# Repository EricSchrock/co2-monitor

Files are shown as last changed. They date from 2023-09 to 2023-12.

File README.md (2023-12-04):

# CO2 Monitor

The goal of this project is to create a network of CO2 sensors for indoor air quality monitoring. See our [project proposal](https://github.com/EricSchrock/co2-monitor/blob/main/submissions/proposal.pdf) and [project report](https://github.com/EricSchrock/co2-monitor/blob/main/submissions/report.pdf) for more detail on our motivation, goals, design, and results.

&nbsp;
## Design

Our system is composed of a variable number of sensor units, which wirelessly report CO2 readings back to a base station. The base station presents these readings via a locally hosted website.

The base station is a Raspberry Pi 4B. We considered a range of [microcontrollers](https://github.com/EricSchrock/co2-monitor/blob/main/docs/microcontroller.md) and [CO2 sensors](https://github.com/EricSchrock/co2-monitor/blob/main/docs/co2-sensor.md) for the sensor unit. We settled on the Raspberry Pi Pico W connected to a Sparkfun ENS160 sensor over I2C.

| System | Sensor Unit |
|---|---|
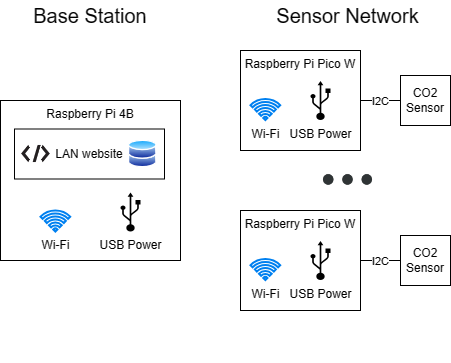
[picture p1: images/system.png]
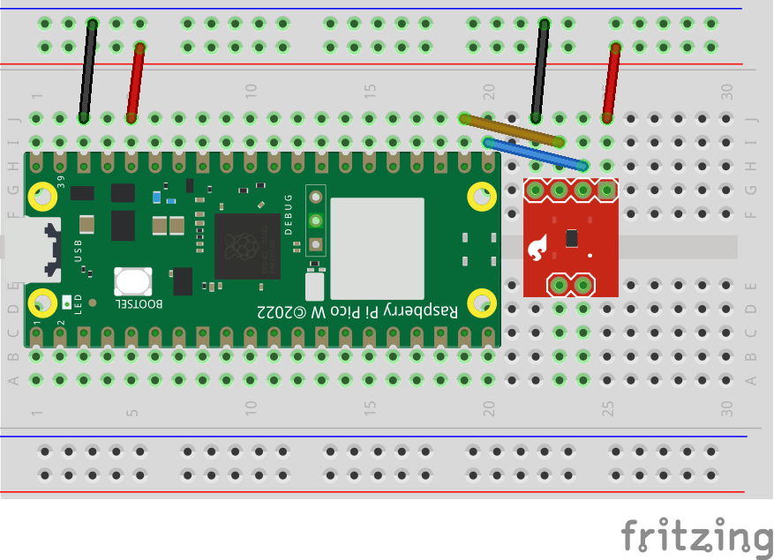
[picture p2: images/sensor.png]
|  |  |

Note: The CO2 sensor shown in the Fritzing diagram above does not match the actual part and is only meant to give a general sense of the design.

&nbsp;
## Bill of Materials (BOM)

### Base Station

| Part | Price* | Supplier  | Link |
|---|---|---|---|
| Raspberry Pi 4B (8 GB) | $75.00 | PiShop.us | https://www.pishop.us/product/raspberry-pi-4-model-b-8gb/ |
| 15W power supply |  $8.00 | PiShop.us | https://www.pishop.us/product/raspberry-pi-15w-power-supply-us-white/ |
| Case |  $5.00 | PiShop.us | https://www.pishop.us/product/raspberry-pi-4-case-red-white/ |
| **Total** | $88.00 | | |

*Price does not include shipping or bulk discounts.

### Sensor Unit

| Part | Price* | Supplier  | Link |
|---|---|---|---|
| Raspberry Pi Pico WH |  $7.00 | PiShop.us | https://www.pishop.us/product/raspberry-pi-pico-wh/ |
| 12.5W power supply |  $8.00 | PiShop.us | https://www.pishop.us/product/raspberry-pi-12-5w-power-supply-us-white/ |
| Sparkfun ENS160 | $19.95 | SparkFun  | https://www.sparkfun.com/products/20844 |
| Half sized bread board |  $4.75 | PiShop.us | https://www.pishop.us/product/half-size-400-pin-diy-breadboard-white/ |
| Breadboard wire kit**  |  $2.32 | PiShop.us | https://www.pishop.us/product/breadboard-wiring-kit/ |
| Headers for ENS160** |  $0.35 | PiShop.us | https://www.pishop.us/product/break-away-headers-40-pin-male-long-centered-pth-0-1/ |
| **Total** | $42.37 | | |

*Price does not include shipping or bulk discounts. \
**One set is enough to furnish at least three sensor units. Price divided by three.

### System

One system with a base station and three sensor units would cost $215.11 (not accounting for shipping). A productionized system could cost much less by buying in bulk and by using a less powerful Raspberry Pi (e.g. less RAM) in the base station. A productionized system would need to add a protective case for the sensor units.

&nbsp;
## Installation

See [src/README.md](https://github.com/EricSchrock/co2-monitor/blob/main/src/README.md) for instructions on setting up the sensor units, server, and web viewer.

&nbsp;
## Tasks

Hardware
  - [x] [First prototype: Just get something working](https://github.com/EricSchrock/co2-monitor/blob/main/docs/first-prototype.md)
    - [x] Diagram initial system architecture
    - [x] Diagram initial sensor unit
    - [x] [Choose which microcontroller to use for the sensor unit](https://github.com/EricSchrock/co2-monitor/blob/main/docs/microcontroller.md)
    - [x] [Choose which CO2 sensor to use](https://github.com/EricSchrock/co2-monitor/blob/main/docs/co2-sensor.md)
    - [x] Create parts list (including tools)
    - [x] Research/test whether to put a capacitor on the power rail between the microcontroller and CO2 sensor (some microcontrollers have built in capacitance on their power outputs)
    - [x] Research/test whether pull up resistors are needed on the I2C SDA and SCL lines between the microcontroller and CO2 sensor (some microcontrollers have built in or configurable pull ups on pins)
  - [x] Second prototype: Consider cost, size, and power usage
    - [x] Choose breadboard size (mini, tiny, half, or half+)
    - [x] Bill of Materials (BOM) including costs, part numbers, and supplier links

Software
  - [x] Sensor readings displayed on sensor unit (via debugger, attached LCD, etc.)
  - [x] Sensor readings displayed on base station (over wifi)
  - [x] Sensor readings displayed on locally hosted website served from the base station
    - [x] Live readings
    - [x] Historical trends
    - [x] Multiple sensors
  - [x] Diagrams (flow charts, activity diagrams, and/or sequence diagram)
    - [x] Sensor unit (sensor.py)
    - [x] Base station (server.py)
    - [x] Whole system

&nbsp;
## Resources

 - <https://www.raspberrypi.com/documentation/microcontrollers/raspberry-pi-pico.html>
 - <https://projects.raspberrypi.org/en/projects/getting-started-with-the-pico/0>
 - <https://datasheets.raspberrypi.com/picow/connecting-to-the-internet-with-pico-w.pdf>
 - <https://cdn.sparkfun.com/assets/3/c/7/5/5/SC-001224-DS-7-ENS160-Datasheet.pdf>

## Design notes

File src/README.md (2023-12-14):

# Sensor Setup

Modify `sensor/config.py` to set `SSID` and `PWD` to match the wifi network
your server is connected to. Set `IP` to the IP of the server and choose a
`PORT` number.

Save `sensor/config.py`, `sensor/ens160.py`, and `sensor/main.py` to the Raspberry
Pi Pico WH on each sensor. One way to do this is with the [Thonny](https://thonny.org/)
editor. The Pico will run `main.py` on power on.

Plug all your sensors into power. The LED on the Pico will blink until a wifi
connection is complete and then stay on until it connects to the server. Then
it will blink each time data is transmitted.

# Server Setup

## Configure Server

Modify the file `server/config.py` to set the Server IP address and Port.
These values must match the configuration hardcoded in the sensors.

Additionally, set the `SENSORS` value to the number of sensors that will be
connected to the system and set the `LOG_PATH` to the full path desired for log
output.

##  Run Server

```sh
python3 server/server.py
```

Add the following line to `/etc/rc.local` to start the server on power on.

```sh
python3 /<full>/<path>/<to>/<repo>/co2-monitor/src/server/server.py &
```

If you have issues with the server dying after a few hours, schedule a reboot
every hour by adding the `0 * * * * root reboot` cron job.

```sh
sudo nano /etc/crontab
```

# Web Viewer Setup

## Create and activate the venv

```sh
python3 -m venv .venv
source .venv/bin/activate
```

## Install requirements

```sh
python3 -m pip install -r requirements.txt
```

## Configure Web Viewer

Modify the dictionary in in `viewer/config.py` to map the sensor
unique IDs to more useful identifiers to be displayed in the webpage.

The unique IDs for the sensors connected to your system can be found
in the server log at `$HOME/.co2_data/server.log`.

## Run Web Viewer for development

To start the web viewer in development mode, run

```sh
flask -A viewer run --debug
```

This will start the http server on you local host at
`http://127.7.7.1:5000`.

## Run Web Viewer for deployment

To start the web viewer in deploy mode, start the http server using
`waitress` with

```sh
waitress-serve viewer:app
```

This will start the http server on `http://0.0.0.0:8080`, which will
serve the webpage from all IP addresses on your pi on port 8080. You can
navigate to `http://<rpi hostname>.local:8080` or `http://<rpi IP>:8080`
to view the web page.

## Using the Web Viewer

The web viewer will default to showing you a chart with all sensor values for
the current day. Using the available form fields, you can optionally specify to
view specific sensors or any other date. If no sensor data is available for the
selected date and sensor, no image will be shown.

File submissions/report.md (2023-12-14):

% **CS 437: Internet of Things** \
  **Final Project Report**
---
urlcolor: cyan
---

## Team

* Eric Schrock (ejs9)
* Devin Schmitz (devinms3)

## Overview

We created a distributed network of CO2 sensors that report back via wifi to a central hub. The hub exposes a web interface on the LAN for accessing the data. This allows us to track variations in CO2 levels throughout a home and over time. This data could be used to understand and improve indoor air quality, leading to healthier lives.

## Motivation

Breathing is one of the most fundamental processes of our lives, but most homes
are only equipped with smoke and carbon monoxide detectors, which just warn
against critically dangerous levels of air polution. High levels of pollutants
like Carbon Dioxide (CO2), particulate matter (PM), and volatile organic
compounds (VOCs) can go unnoticed, contributing to drowsiness, illness, and
poor cognitive function, among many other potential poor health
outcomes[^20][^21][^22].

Large pollutants can be filtered out by a good HVAC or air filtration system,
but small asphyxiants such as CO2 and VOCs are best managed with proper air
ventilation. However, the exchange of fresh outdoor air for indoor air works
against the mission of modern HVAC, door, and window systems, which attempt to
maintain a consistent internal climate (in spite of the surrounding
environment) by _avoiding_ the exchange of indoor and outdoor air.

It is easy to open a window during the spring and fall when the weather is
nice, but knowing when it is necessary to open a window for proper air
circulation during the cold winter or hot summer can be a challenge. Having a
window open all the time wastes energy heating excess fresh air, but fatigue
and headache from poor air quality only exacerbates common ailments like
seasonal depression.

The first step to balancing this tension is having data. CO2 serves as a good
proxy for appropriate air ventilation in general. CO2 is a direct byproduct of
respiration and combustion, so indoor levels rise throughout the day as we
breath and use gas appliances like stoves, hot water heaters, and furnaces. By
monitoring indoor CO2 levels, we can have a better idea of when there is
adequate ventilation and when more fresh air exchange is needed.

However, proper air monitoring requires a distributed network. A single sensor,
though useful, does not provide a comprehensive picture of the air quality
throughout a home (especially in homes with poor overall ventilation). A
network of sensors also reduces inaccuracy due to any single faulty sensor
reading and keeps the system more robust to sensor failures. Additionally, many
existing air monitoring solutions are cost prohibitive to deploy across a home,
with individual sensors costing up to $230[^23] and coming with a list of extra
and unnecessary features like onboard data processing and display.

We designed a simple, low cost CO2 sensor that can be deployed throughout a
home for real time monitoring of air quality with a single central hub for
processing and displaying the data via a convenient web application on the
local area network.

[^20]: <https://ehp.niehs.nih.gov/doi/10.1289/ehp.1510037>
[^21]: <https://papers.ssrn.com/sol3/papers.cfm?abstract_id=4296077>
[^22]: <https://www.niehs.nih.gov/health/topics/agents/air-pollution/index.cfm>
[^23]: <https://www.airthings.com//wave-plus>

## Technical Approach

Our overall system consists of a base station connected to a network of sensors over wifi. The base station is a Raspberry Pi 4B running a server. Sensors connect to the server and periodically report CO2 measurements. The base station then presents those measurements on a website available on the local area network.

Each sensor consists of a Raspberry Pi Pico WH connected to a CO2 sensor over I2C. Each sensor runs a client that is responsible for connecting to the server on the base station, reading CO2 measurements, and sending those measurements to the base station.

System Architecture

Sensor Layout[^52]

[^52]: The CO2 sensor shown in figure 2 does not match the actual part and is only meant to give a general sense of the design.

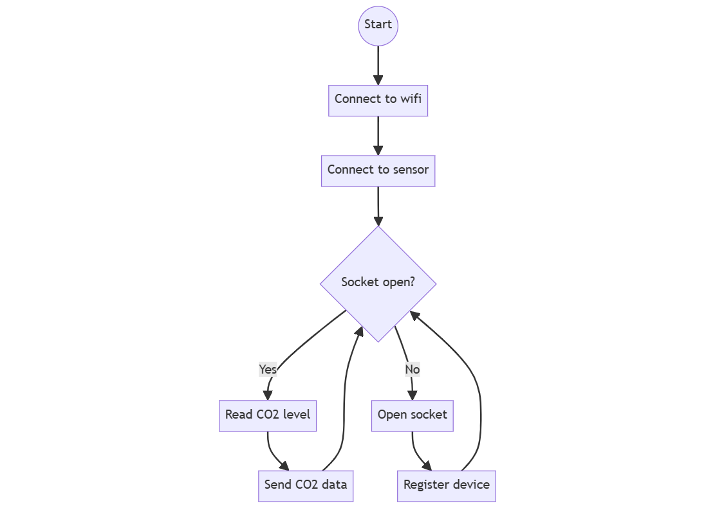
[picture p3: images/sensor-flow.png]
Sensor Flowchart


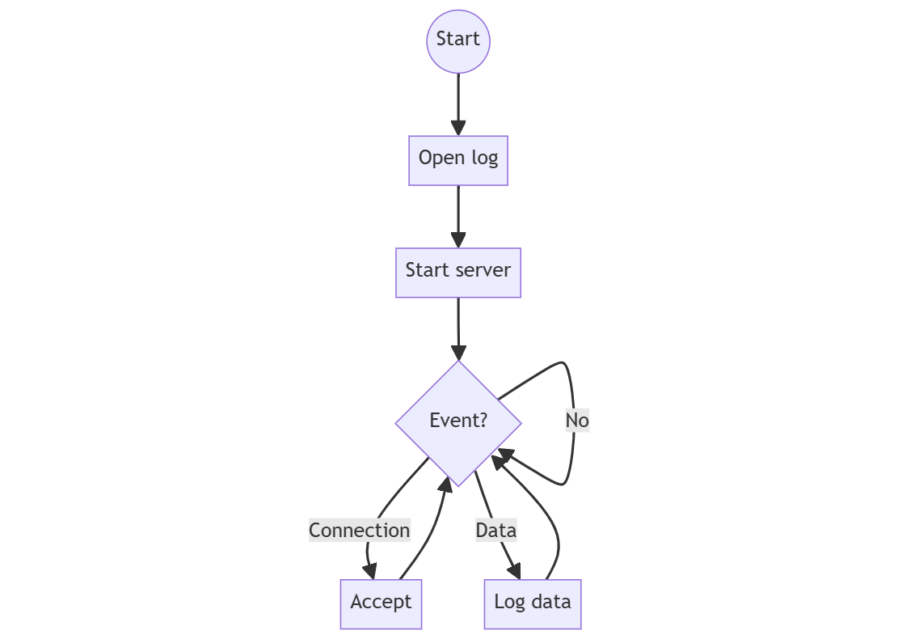
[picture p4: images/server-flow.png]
Server Flowchart


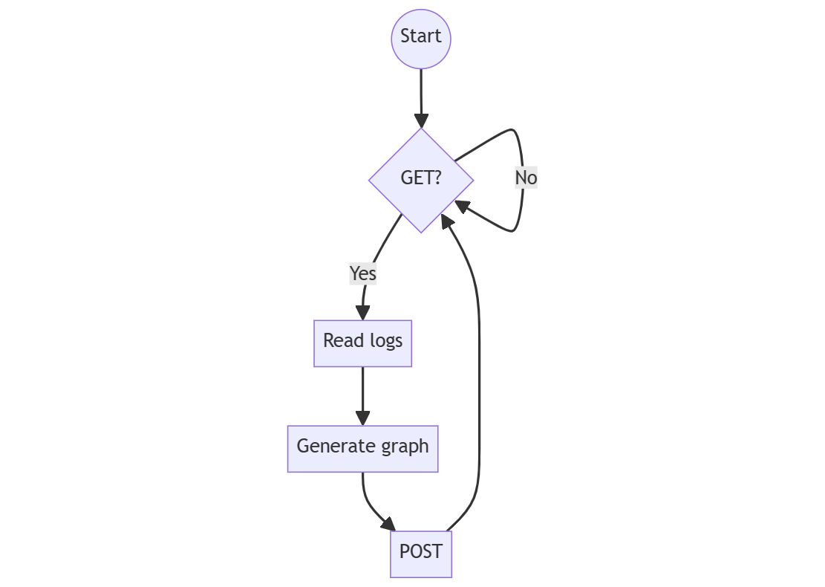
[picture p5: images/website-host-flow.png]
Website Host Flowchart


\pagebreak
## Implementation Details

### Sensors

We spent a significant amount of time comparing[^1] different options for the microcontroller on our sensors units. We started our search with six different Arduino variants (five Nano variants and the Micro). We looked at price, availability, breadboard compatibility, power and IO options, and connectivity (wifi, Bluetooth, and BLE). We were leaning towards the Arduino Nano 33 IoT[^2] when we found the Raspberry Pi Pico WH[^3] [^4], which checked all our boxes but for a much cheaper price ($7 vs $27).

[^1]: <https://github.com/EricSchrock/co2-monitor/blob/main/docs/microcontroller.md>
[^2]: <https://store-usa.arduino.cc/products/arduino-nano-33-iot-with-headers>
[^3]: <https://www.raspberrypi.com/documentation/microcontrollers/raspberry-pi-pico.html>
[^4]: <https://www.pishop.us/product/raspberry-pi-pico-wh-pre-soldered-headers>

The Pico comes with both C/C++[^5] and Python[^6] SDKs. We are both embedded C programmers for our day job, so we picked the Python SDK to get some experience with MicroPython[^7]. Additionally, the simplicity of Python fit with a simple prototype on a tight timeline.

[^5]: <https://datasheets.raspberrypi.com/pico/raspberry-pi-pico-c-sdk.pdf>
[^6]: <https://datasheets.raspberrypi.com/pico/raspberry-pi-pico-python-sdk.pdf>
[^7]: <https://micropython.org/>

We also considered[^8] multiple CO2 sensors, before settling on the ENS160[^9]. Our criteria were price, availability, breadboard compatibility, and power and IO options.

[^8]: <https://github.com/EricSchrock/co2-monitor/blob/main/docs/co2-sensor.md>
[^9]: <https://www.sciosense.com/wp-content/uploads/documents/SC-001224-DS-9-ENS160-Datasheet.pdf>

Additionally, we had to consider whether to choose a true CO2 sensor or an equivalent CO2 (eCO2[^10]) sensor. eCO2 sensors don't measure CO2 directly. Instead, they measure total volatile organic components (TVOC) and use that measurement to estimate the CO2 level. eCO2 sensors are much cheaper but are less accurate. We chose to go with an eCO2 sensor, as price is a big factor in our design. Having multiple sensor units allowed us to sanity check the reported values and notice anomalies. Given this, the eCO2 sensor was accurate enough to observe trends and draw conclusions. More on this in the CO2 Data Analysis portion of the Results section.

[^10]: <https://electronics360.globalspec.com/article/17986/what-are-eco2-sensors>

The SparkFun ENS160[^11] came with the option to communicate over I2C or SPI. We chose I2C because it was simpler to implement in MicroPython.

[^11]: <https://www.sparkfun.com/products/20844>

The Pico supports wifi, Bluetooth, and BLE. We initially planned to use BLE to communicate with the server, but implementing wifi communication turned out to be much simpler. Additionally, power usage turned out to be less of a concern than we initially thought because we chose to power the sensor units off wall power instead of batteries.

We chose to connect up the Pico and ENS160 on a half sized breadboard and to power them both through the micro USB port on the Pico. We built both dev units and full prototypes.

Development Unit
Full Prototypes
\begin{figure}[!h]
\caption{Development Unit (left) and Full Prototypes (right)}
\end{figure}

The software development for the sensor unit was relatively straight forward. We wrote simple programs to aid hardware bring up, first to blink the Pico LED and then to turn the Pico LED on when we breathed on the CO2 sensor. Then we created a simple program that connects to wifi, connects to the CO2 sensor via I2c, connects to the server, and then periodically reads and reports the CO2 level (see the sensor flow chart above in the Technical Approach section).

### Server

In choosing the hardware for the central server, we quickly decided to use the
Raspberry Pi 4B[^41] that we had both already purchased for earlier labs in the
class. The Raspberry Pi 4B provides a builtin wifi module to connect to the
sensor units and sufficient processing power and RAM to host a basic webpage
and do minimal data processing. In fact, the Raspberry Pi 4B far exceeded our
basic requirements for a server. If we were going to productionize the system,
we would explore using a smaller Raspberry Pi with less RAM or potentially an
even simpler SBC to reduce the cost of the system.

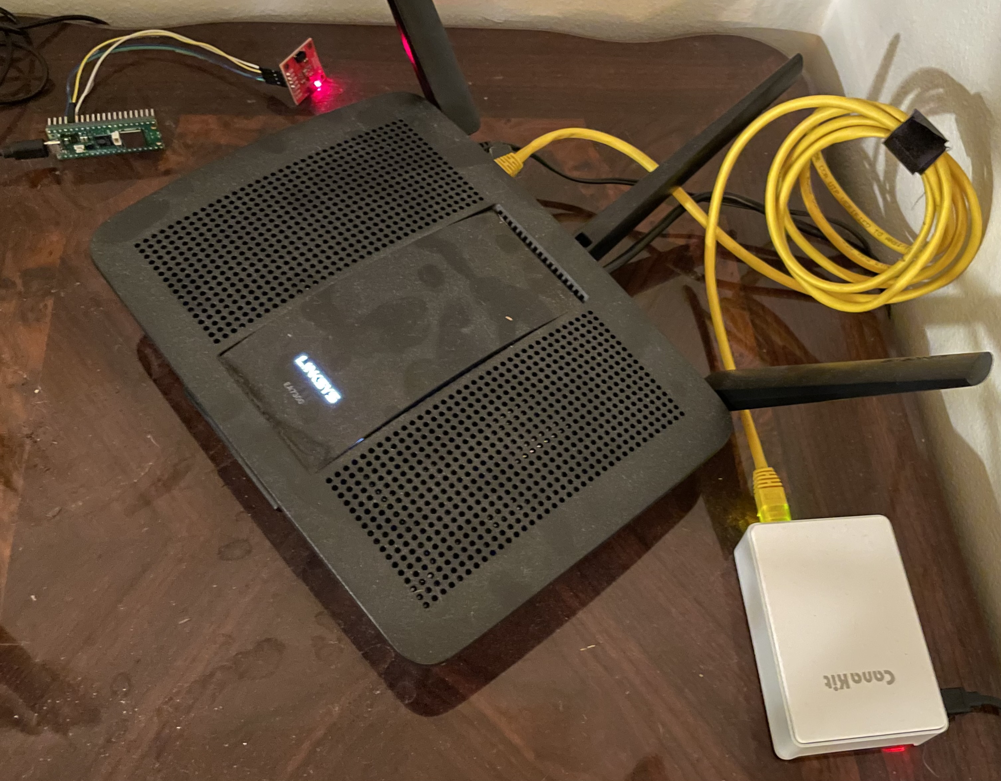
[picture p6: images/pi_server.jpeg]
Devin

Eric
\begin{figure}[!h]
\caption{Raspberry Pi Hubs Connected to Sensors via Wifi}
\end{figure}

In designing the server software, our goal was simplicity, reliability, and
minimal dependencies. We wrote the entire server application using just the
Python standard library. We started with a simple server that could connect to
one sensor using sockets, using what we had learned from our previous labs.
Then, we extended the server and our knowledge of sockets programming by
incorporating a selector[^42] to handle multiple socket connections to
different sensors. Throughout the server development, we took advantage of the
ability to create socket pairs on a single device to emulate a sensor network
locally for debugging, which allowed us to parallelize the sensor and server
development.

When it came to storing CO2 data, we considered integrating a proper database.
However, after looking into it, even a simple SQL database[^43] seemed like
unnecessary overhead and complexity for the data we were storing. We settled on
storing the data in basic CSV files to make both writing the data and loading
it for later analysis easy. Our first iteration of data logging had a unique
file for each sensor, which contained the full date-time timestamp for each CO2
reading. It quickly became apparent that this was suboptimal for two reasons.
First, having all CO2 data from one sensor in a single file meant that
significantly more data would have to be parsed to analyze a small time window
of data. Second, including the date in every timestamp was a significant
duplication of data and thus waste of memory. We settled on splitting up the
data by date instead, so that each day's readings would be stored in a
directory with a CSV file for each sensor that only contained the timestamps
for the CO2 readings.

One challenge I (Eric) faced was the server process on the Pi dying every few hours. My solution was to reboot the Pi every hour via the Linux `cron` utility. I edited `/etc/rc.local` to restart the server on each reboot, allowing me to capture data over long periods without babysitting (e.g overnight). Devin's system never exhibited this issue.

[^41]: <https://www.raspberrypi.com/products/raspberry-pi-4-model-b/>
[^42]: <https://docs.python.org/3/library/selectors.html>
[^43]: <https://docs.python.org/3/library/sqlite3.html>

### Website

Since neither of us has web development experience, we were learning
everything as we went. This meant simplicity and basic functionality were high
priorities as we chose software stacks for our web application. We are both
comfortable with Python, so it made sense to use a backend Python framework. We
considered two dominant web frameworks: Django[^31] and Flask[^32]. Each has
pros and cons, and both are widely used in industry. However, we settled on
Flask for two key reasons. First, it is faster to get a minimal web application
up and running from scratch in Flask. Second, Flask uses `jinja2`[^37]
templates by default, which we were already familiar with.

From there, the development of the website evolved in stages. First, we setup
a basic "Hello World" page to verify that we could successfully run our Flask
application. Then, we upgraded the application to include a request form for a
date, which we initially just echoed to the webpage. Finally, we updated the
web app to display the list of CO2 reading times and values for the selected
date.

At this stage, we had to decide on a software stack to generate the most
important part of the web application: a chart of the data. We considered
three options: Chart.js[^33], Matplotlib[^34], and plotlib[^35] with
WebAssembly[^36]. These three options vary significantly, from the language
used (Javascript, Python, and Rust respectively) to how they integrate into the
Flask application. While the Rust and WebAssembly option was interesting to
explore, WebAssembly is a relatively new technology and doesn't have the same
level of existing examples and documentation as the more established
competitors. Chart.js was a compelling option, with support for dynamic and
interactive charts in a web-native language. However, Matplotlib had a few
great examples for integrating charts into a webpage and was already familiar
to us, so it won out as the best option to meet the goals and timelines of this
project. Additionally, in brief prototyping, a webpage with a matplotlib image
reloaded nearly instantaneously, while plotting the same data with Chart.js had
a noticeable (several second) delay.

Finally, we needed to choose a WSGI server to host our web application. We
considered several of the options on Flask's list of recommended self-hosted
WSGI servers[^38]. We chose Waitress[^39] because it is a pure Python
application with no dependencies, which made it easy to include in our project.

[^31]: <https://docs.djangoproject.com/en/5.0/>
[^32]: <https://flask.palletsprojects.com/en/3.0.x/>
[^33]: <https://www.chartjs.org/>
[^34]: <https://matplotlib.org/stable/index.html>
[^35]: <https://docs.rs/plotlib/latest/plotlib/>
[^36]: <https://rustwasm.github.io/>
[^37]: <https://jinja.palletsprojects.com/en/3.1.x/templates/>
[^38]: <https://flask.palletsprojects.com/en/3.0.x/deploying/>
[^39]: <https://docs.pylonsproject.org/projects/waitress/en/stable/>

## Results

### Project Timeline

Overall, the project probably took a little over the projected 45 hours. The bookends, the initial design decisions and the project report, took much more time than planned, but the hardware bring up was exceptionally smooth and we did not need the planned second prototype. Our time estimates for the website were about right.

### Project Objectives

At a high level, we met the objective we laid out in our project proposal, which was "to create a network of CO2 sensors with a web interface" to allow "distributed monitoring of indoor air quality." Our proposal also laid out the objectives of "simple, low cost, low energy" sensors.

We met the objective of simple sensors. We avoided extra functionality that would have increased cost and complexity (e.g. multi-function sensors or extra website features). We also kept the setup instructions[^12] simple (for a prototype).

[^12]: <https://github.com/EricSchrock/co2-monitor/blob/main/src/README.md>

As our design evolved from a battery powered sensor to a wall powered sensor, we dropped the objective of being low energy. This allowed us to make tradeoffs in favor of simplicity and speed. For example, it allowed us to keep our code simple by using wifi instead of BLE and by not implementing any low power modes. Now that we have a working prototype that has proved it's value, power usage optimization would be a valuable consideration for a second prototype.

We also met the objective of low cost sensors, with each sensor unit costing roughly $40. A productionized sensor unit, benefiting from economies of scale, could cost even less.

The base station prototype is pricier at $88. This is largely because we used the 8 GB Raspberry Pi 4B because it is what we had on hand. Using the 1 GB model would drop the base station cost to $48. A simple website doesn't take much compute power. A productionized version of the base station could use an even cheaper processor. It's even possible that one of the sensor units could function as the server for the rest of the sensor network.

**Sensor Unit**

| Part | Price[^44]  |
|---|---|
| Raspberry Pi Pico WH |  $7.00[^45] |
| 12.5W power supply |  $8.00[^46] |
| Sparkfun ENS160 | $19.95[^47] |
| Half sized bread board |  $4.75[^48] |
| Wires and headers | ~$0.30 |
| **Total** | $40.00 |

**Base Station**

| Part | Price[^44]  |
|---|---|
| Raspberry Pi 4B (8 GB) | $75.00[^49] |
| 15W power supply |  $8.00[^50] |
| Case |  $5.00[^51] |
| **Total** | $88.00 |

[^44]: Price does not include shipping or bulk discounts.
[^45]: <https://www.pishop.us/product/raspberry-pi-pico-wh/>
[^46]: <https://www.pishop.us/product/raspberry-pi-12-5w-power-supply-us-white/>
[^47]: <https://www.sparkfun.com/products/20844>
[^48]: <https://www.pishop.us/product/half-size-400-pin-diy-breadboard-white/>
[^49]: <https://www.pishop.us/product/raspberry-pi-4-model-b-8gb/>
[^50]: <https://www.pishop.us/product/raspberry-pi-15w-power-supply-us-white/>
[^51]: <https://www.pishop.us/product/raspberry-pi-4-case-red-white/>

\pagebreak
### CO2 Data Analysis

One question we had was whether our sensors would be accurate enough to provide useful data. We found that the data trends were reliable enough to interpret and act on. For example, figure 8 shows around thirteen hours of CO2 data that is readily attributable to the day's activities.

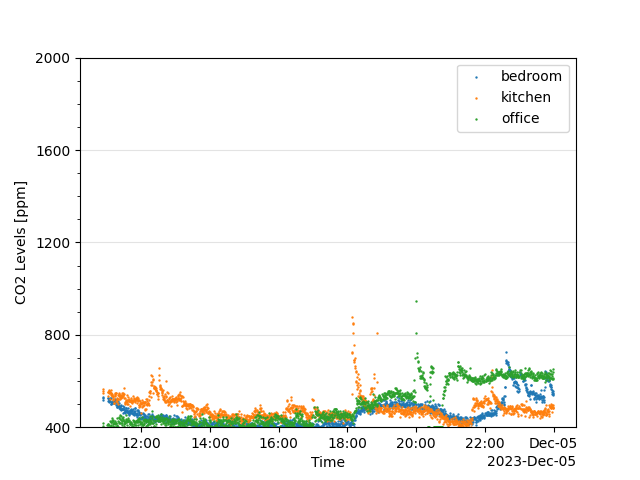
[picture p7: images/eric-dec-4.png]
CO2 Data from Eric's Home (12/4/23)


1. 11 AM - 2 PM: Bedroom CO2 level drops from its nighttime high.
2. 12 - 1 PM: Kitchen CO2 level jumps as my wife and I (Eric) eat lunch.
3. 1 - 6:15 PM: Bedroom sits empty and has the lowest CO2 level. I sit at my desk in my office and my wife moves around the kitchen and adjoining living room. The kitchen CO2 level is higher than the office CO2 level because humans breath out more CO2 when we are active.
4. 6:15 PM: Kitchen CO2 level spikes when we vent the pressure cooker and then dissipate to the rest of the house.
5. 6:30 - 7 PM: Kitchen CO2 level jumps as my wife and I eat supper.
6. 7 - 9:30 PM: My wife leaves for time with friends and I return to my office. Kitchen CO2 level drops below that of the office.
7. 8:15 PM: I briefly open a window in my office. The office CO2 level drops to the minimum sensor value of 400 ppm, but jumps back up as soon as I close the window.
8. 8:30 - 8:45 PM: I open a window in my office for 15 minutes. The office CO2 level again drops to the minimum, but jumps back as soon as the window is closed.
9. 9:30 - 10:15 PM: My wife returns and we spend time together in the living room, near the kitchen. The kitchen CO2 level jumps.
10. 10:15 PM: We go to bed. Kitchen CO2 level drops and bedroom CO2 level jumps.

The sensors do have a couple issues to keep in mind. First, as explained in the section on implementation details, they are measuring eCO2 which is an estimate of CO2 levels derived from TVOC levels. TVOCs can spike without CO2 spiking. For example, the data above shows a spike in the office CO2 levels at around 8 PM. This was from running a paper shredder near the sensor.

Second, the sensor results can occasionally get stuck at a high offset until they are power cycled. The CO2 level in the office jumped significantly the evening of December 4th (figure 8) and remained high into the next day (figure 9). I first tried opening windows throughout the house from 10:15 - 10:30 AM. The other rooms responded to this, but the office CO2 level jumped back up as soon as the windows were closed. At around noon, I power cycled the office sensor.

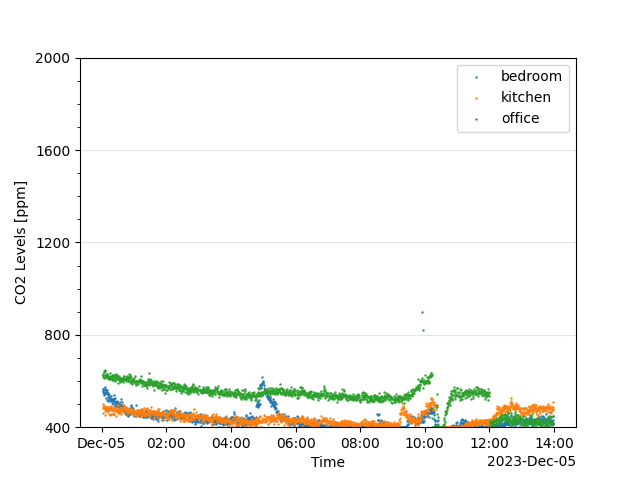
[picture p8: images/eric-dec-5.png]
CO2 Data from Eric's Home (12/5/23)


There were other interesting trends we observed in the data.
For example, the week of Thanksgiving I (Devin) was out of the home,
and all three CO2 sensors consistently measured low and unchanging CO2 levels (figure 10).
This indicates that practically all significant CO2 production in the home is
linked to my activity in some way, rather than to furnace or hot water heater
cycles.

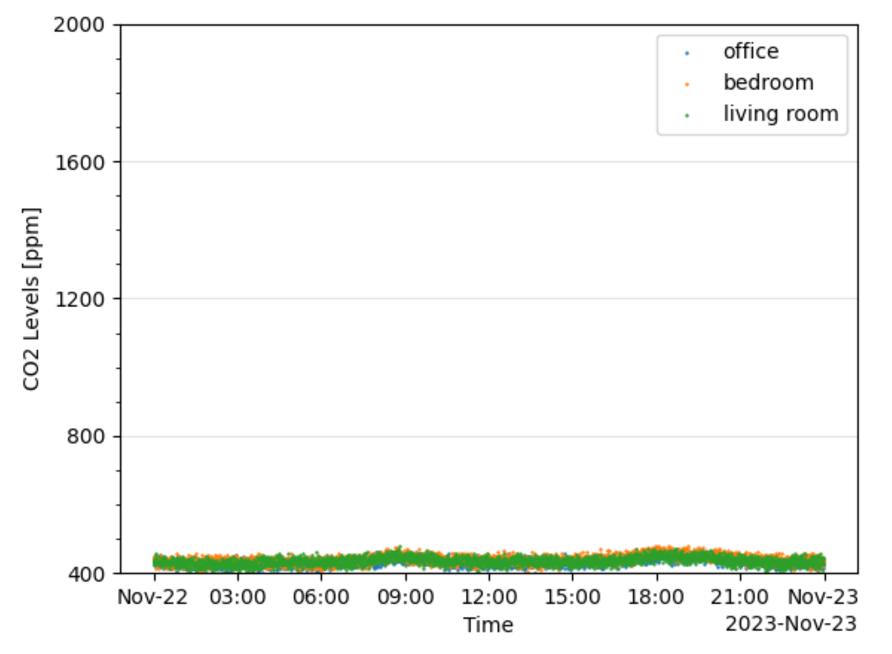
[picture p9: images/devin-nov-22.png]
CO2 from Devin's Vacant Home (11/22/23)


Another pattern I noticed is a cyclic rising and
falling CO2 levels in the bedroom during early morning hours (figure 11).
The cycles appear every night and only in the bedroom, leading
me to wonder if they are related to sleep cycles.
Correlating the data to a sleep tracker would be a fascinating follow on project.

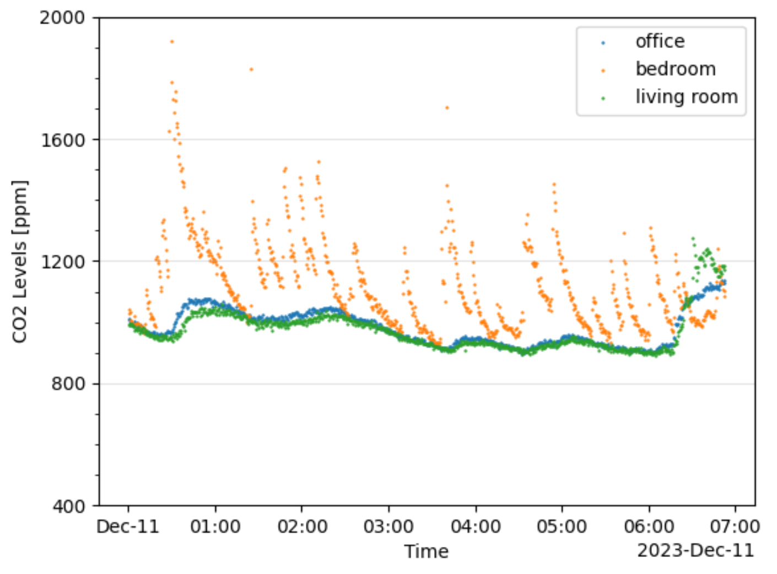
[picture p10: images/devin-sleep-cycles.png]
Cycling CO2 from Devin's Early Morning Bedroom


Despite some issues, our sensor data correlated well to real world events. As long as the limitations we listed are kept in mind, we believe it is accurate enough to drive meaningful decisions. Examples range from whether to open a window in the winter to whether to invest in a new HVAC that cycles in outdoor air in response to high indoor CO2 levels.

\pagebreak
## Demo Videos

We recommend watching these videos on a large screen and/or setting your video player to HD/1080p.

[Sensor Demo (part 1)](https://drive.google.com/file/d/1a0BKiZZGW25rD8P6CbH9XDvGnOE_0py2/view?usp=drive_link)

[Sensor Demo (part 2)](https://drive.google.com/file/d/1c5ptHw5lVUbp_UhcpIysfnRmQVWlg9hd/view?usp=drive_link)

[Server Demo](https://drive.google.com/file/d/1L9Yu0_yAXi-gdyQ4_XYW-zPx3bfIi20b/view?usp=sharing)

[Website Demo](https://drive.google.com/file/d/16GgEEeUNtK0YC5ep9FUWzXnTIX9rkhJd/view?usp=sharing)

## Project Repository

<https://github.com/EricSchrock/co2-monitor>

## What We Learned

### Eric

Two of the key skills I learned in this project were networking via the Python sockets library and how to configure Linux using the `/etc/rc.local` file and `cron` jobs. Both were completely new to me and are valuable experiences for the future.

On a different note, I was surprised by how easy it was to get the project up and running on the Raspberry Pi Pico with MicroPython. I'm used to embedded boards being much more painful to bring up. Perhaps some personal projects I thought would be too time consuming are actually in reach!

This project also taught me about the health impacts of high concentrations of CO2 in indoor spaces. This is important knowledge to help me stay sharp. As a remote worker, I can put what I've learned to use by opening my office windows at key times.

### Devin

I learned a great deal from working with the hardware in this lab. I soldered
header pins for the first time. I gained valuable experience reading the ENS160
datasheet to understand how to read sensor values over I2C. I learned how to
use `minicom` to view serial data from the Pi Pico and how to prototype
micropython on the Pi Pico from the interactive micropython REPL.

This project significantly expanded my understanding and confidence in socket
programming, which I had only just learned in previous class labs. It also
challenged me to write a safe and robust server application.

Building the webpage may have taught me the most. Weighing different Python web
frameworks gave great insight into the infrastructure underlying websites and
web applications that I use on a daily basis. Actually deploying a functional
web form involved more pieces than I knew and gave me a new respect for web
development.

### If We Had More Time

If we were to take this project further, we would have three main goals. The first would be to increase the accuracy of the sensor readings, either by tuning them with temperature and humidity readings reported to them by the base station or by automatically power cycling the ENS160 CO2 sensor periodically.

Second, we would expand the functionality of the website. We would add the ability to save timestamped notes to mark and explain phenomena in the data. We would also make the time interval for the display configurable. Additionally, we would add simple statistics, such as the max and average over the selected time interval.

The third goal would be to condense the sensor unit into a wall wart with a protective housing. We would look into 3D printing for the case and into a custom PCB to fit in a smaller form factor.

## Conclusion

In conclusion, we accomplished the high level goal of our project, to prototype a distributed, networked, and affordable CO2 monitoring solution. Along the way, we tried new technologies, built new skills, and gained a deeper understanding of the quality of the air in our homes and of how it impacts our health.

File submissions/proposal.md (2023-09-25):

% **CS 437: Internet of Things** \
  **Final Project Proposal**
---
urlcolor: cyan
---

## Overview

We propose to create a network of CO2 sensors with a web interface. Our goal is
distributed monitoring of indoor air quality.

## Group

One of the motivations of this project is to stretch us beyond what we already know. We have included short professional biographies to illustrate our current skills and how we hope this project extends them.

### Eric Schrock (ejs9)

My Computer Engineering curriculum was a mixture of Electrical Engineering and Computer Science in addition to courses on embedded programming and digital logic design. After graduation, I spent four years in the automotive industry working on advanced driver-assistance systems (ADAS). Devin and I now work together on the root of trust (RoT) for secure servers.

I am most comfortable programming bare metal (no OS) embedded C on microcontrollers. I've also played with various sensors and displays. I have very little experience with networking or web development and I anticipate our project challenging me to grow in these areas.

### Devin Schmitz (devinms3)

My formal Computer Science background consists of only a few introductory
programming courses, algorithms, and data structures, but I have a strong
background in applied mathematics and a broad knowledge of the physical
sciences. My professional experience is all centered around bare metal embedded
C, but I also have a fair knowledge of Linux operating systems and data
analysis with numerical Python. I anticipate most everything else involved in
the project will be a learning opportunity for me. In particular, I have very
little experience with networking and web development, and no experience with
javascript.

## Motivation

Breathing is one of the most fundamental processes of our lives, but most homes
are only equipped with smoke and carbon monoxide detectors, which just warn
against critically dangerous levels of air polution. High levels of pollutants
like Carbon Dioxide (CO2), particulate matter (PM), and volatile organic
compounds (VOCs) can go unnoticed, contributing to drowsiness, illness, and
poor cognitive function, among many other potential poor health
outcomes[^1][^2][^3].

Large pollutants can be filtered out by a good HVAC or air filtration system,
but small asphyxiants such as CO2 and VOCs are best managed with proper air
ventilation. However, the exchange of fresh outdoor air for indoor air works
against the mission of modern HVAC, door, and window systems, which attempt to
maintain a consistent internal climate (in spite of the surrounding
environment) by _avoiding_ the exchange of indoor and outdoor air.

It is easy to open a window during the spring and fall when the weather is
nice, but knowing when it is necessary to open a window for proper air
circulation during the cold winter or hot summer can be a challenge. Having a
window open all the time wastes energy heating excess fresh air, but fatigue
and headache from poor air quality only exacerbates common ailments like
seasonal depression.

The first step to balancing this tension is having data. CO2 serves as a good
proxy for appropriate air ventilation in general. CO2 is a direct byproduct of
respiration and combustion, so indoor levels rise throughout the day as we
breath and use gas appliances like stoves, hot water heaters, and furnaces. By
monitoring indoor CO2 levels, we can have a better idea of when there is
adequate ventilation and when more fresh air exchange is needed.

However, proper air monitoring requires a distributed network. A single sensor,
though useful, does not provide a comprehensive picture of the air quality
throughout a home (especially in homes with poor overall ventilation). A
network of sensors also reduces inaccuracy due to any single faulty sensor
reading and keeps the system more robust to sensor failures. Additionally, many
existing air monitoring solutions are cost prohibitive to deploy across a home,
with individual sensors costing up to $230[^4] and coming with a list of extra
and unnecessary features like onboard data processing and display.

We propose to address these issues by designing simple, low cost, low energy
CO2 sensors that can be deployed throughout a home for real time monitoring of
air quality, with a single central hub for processing and displaying the data
via a convenient web application on the local area network.

[^1]: <https://ehp.niehs.nih.gov/doi/10.1289/ehp.1510037>
[^2]: <https://papers.ssrn.com/sol3/papers.cfm?abstract_id=4296077>
[^3]: <https://www.niehs.nih.gov/health/topics/agents/air-pollution/index.cfm>
[^4]: <https://www.airthings.com//wave-plus>

\pagebreak

## Timeline

* Since we both lack web and networking experience, we set higher time estimates for related milestones
* "CP" stands for "Checkpoint"

+--------------+-------------------------------------------------+-----------+
| **Week**     | **Milestones**                                  | **Hours** |
+==============+=================================================+===========+
| 6            | - Initial design decisions                      |         4 |
|              | - Parts ordered for initial prototype           |         1 |
+--------------+-------------------------------------------------+-----------+
+--------------+-------------------------------------------------+-----------+
| 7            | - Components individually tested                |         4 |
|              | - Initial prototype built                       |         2 |
+--------------+-------------------------------------------------+-----------+
+--------------+-------------------------------------------------+-----------+
| 8            | - Local display of CO2 readings                 |         3 |
|              | - Test plan showing CO2 level variation         |         1 |
+--------------+-------------------------------------------------+-----------+
+--------------+-------------------------------------------------+-----------+
| **CP 1**     | **Local CO2 level display**                     |           |
+--------------+-------------------------------------------------+-----------+
+--------------+-------------------------------------------------+-----------+
| 9            | - Second prototype designed                     |         3 |
|              | - Parts ordered for second prototype            |         1 |
+--------------+-------------------------------------------------+-----------+
+--------------+-------------------------------------------------+-----------+
| 10           | - New components individually tested            |         3 |
|              | - Second prototype assembled and tested         |         2 |
+--------------+-------------------------------------------------+-----------+
+--------------+-------------------------------------------------+-----------+
| 11           | - LAN website displays live CO2 reading         |         5 |
+--------------+-------------------------------------------------+-----------+
+--------------+-------------------------------------------------+-----------+
| **CP 2**     | **LAN access to live data**                     |           |
+--------------+-------------------------------------------------+-----------+
+--------------+-------------------------------------------------+-----------+
| 12           | - Website shows historical trends               |         5 |
+--------------+-------------------------------------------------+-----------+
+--------------+-------------------------------------------------+-----------+
| 13           | - Website shows multiple sensors                |         5 |
+--------------+-------------------------------------------------+-----------+
+--------------+-------------------------------------------------+-----------+
| **CP 3**     | **Fully featured website**                      |           |
+--------------+-------------------------------------------------+-----------+
+--------------+-------------------------------------------------+-----------+
| 14           | - Design documents updated                      |         2 |
+--------------+-------------------------------------------------+-----------+
+--------------+-------------------------------------------------+-----------+
| 15           | - Final report and demo video                   |         4 |
+--------------+-------------------------------------------------+-----------+
+--------------+-------------------------------------------------+-----------+
| Hours        |                                                 |        45 |
+--------------+-------------------------------------------------+-----------+

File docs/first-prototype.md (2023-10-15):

# First Prototype

The goal of our first prototype is to just get something working. Additionally, we need to acquire and learn any tools we don't already have (soldering iron, logic analyzer, etc.).

&nbsp;
## Layout (sensor unit)



&nbsp;
## Parts List

Some of these items are optional. The parts list for the second prototype will be more precise.

| Item | Notes |
|---|---|
| Raspberry Pi 4B | |
| Raspberry Pi Pico WH | |
| USB-C cable for PI 4B | |
| Micro USB cable for Pico | Needs to support power and data |
| USB wall wart for Pico | Use wall power for sensor units |
| Sparkfun ENS160 | |
| Breadboard | Half or full size should work |
| Breadboard wire kit | |
| Resistor and capacitor kit | For pull ups and power smoothing |
| Soldering iron | For CO2 sensor |
| Soldering station | With clips to hold components |
| Oscope or logic analyzer | For I2C debugging |

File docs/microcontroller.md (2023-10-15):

## Microcontroller Comparison

| Microcontroller | Price* | Shipping  | Headers** | 3V3 | 5V  | I2C | BT  | BLE | Fritzing  | Link |
|---|---|---|---|-----|-----|---|-----|-----|---|---|
| Micro | $24.90 | 3 days | Yes | Yes | Yes | Yes |  No |  No | Yes**** | https://store-usa.arduino.cc/products/arduino-micro |
| Nano | $24.90 | 3 days | Yes | Yes | Yes | Yes |  No |  No | Yes | https://store-usa.arduino.cc/products/arduino-nano |
| Nano Every | $14.70 | 3 days | Yes | Yes | Yes | Yes |  No |  No | Yes**** | https://store-usa.arduino.cc/products/arduino-nano-every-with-headers |
| Nano 33 BLE | $29.30 | 3 days | Yes | Yes | Yes | Yes*** | Yes | Yes | Yes**** | https://store-usa.arduino.cc/products/arduino-nano-33-ble-with-headers |
| Nano 33 IoT | $27.00 | 3 days | Yes | Yes | Yes | Yes*** | Yes | Yes | Yes**** | https://store-usa.arduino.cc/products/arduino-nano-33-iot-with-headers |
| Nano ESP32 | $21.00 | 3 days | Yes | Yes | Yes | Yes | Yes |  No | No | https://store-usa.arduino.cc/products/nano-esp32-with-headers |
| RPi Pico WH |  $7.00 | 1-5+ days | Yes | Yes | Yes | Yes | Yes | Yes | Yes | https://www.sparkfun.com/products/20174 |

RPi Pico WH just went out of stock on Sparkfun, it is also available at
<https://www.pishop.us/product/raspberry-pi-pico-wh/>

*Does not include shipping \
**Breadboard compatible headers \
***Built in pull up resistors \
****Custom Fritzing part available to download

&nbsp;
## Microcontroller Choice

We started our search with the Arduino Micro and Nano because we want to keep our sensor units small and cheap. We plan to build our prototypes on small breadboards, so having pre-soldered headers that fit breadboard rails will keep things simple. We anticipate communicating with our CO2 sensor over I2C but we don't know yet whether the sensor we choose will require 3V3 or 5V power. Power usage is also a consideration for our project so we'd like to use BLE rather than vanilla Bluetooth or Wi-Fi if possible. We were initially leaning towards the Arduino Nano 33 IoT, but ended up landing on the Raspberry Pi Pico WH for the reasons below.

  - Low Cost: Only $7.00 per unit
  - Versatile Power input: 5V via micro USB or 1.8V - 5.5 V from any power
    source directly to VSYS (battery, etc.) with automatic conversion to 3V3
    via onboard buck-boost SMPS.
  - Full Wireless Capabilities: 2.4GHz wireless interface (Infineon CYW4343)
    - Single band (2.4 GHz) Wifi 4 (802.11n)
    - WPA3
    - softAP (up to 4 clients)
    - Bluetooth 5.2:
      - Support for Bluetooth LE Central and Peripheral roles
      - Support for Bluetooth Classic
  - Available with soldered 0.1 inch headers
  - 30 mulit-function GPIO with 1.8 - 3.3V I/O
  - 2 UART, 2 SPI, 16 PWM, 4 ADC channels
  - 1 timer with 4 alarms, 1 real time clock
  - 2 Programmable I/O (PIO) blocks, 8 state machines total
  - Fritzing Part: <https://www.raspberrypi.com/documentation/microcontrollers/raspberry-pi-pico.html>

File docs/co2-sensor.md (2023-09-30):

## CO2 Sensor Comparison

| Source | Price* | Shipping | Vin | IO  | Link |
|---|---|---|---|-----|---|
| Amazon | $13.99 | 1 day  | 3V3 or 5V | I2C | https://www.amazon.com/EC-Buying-Formaldehyde-Monitoring-Multi-Pixel/dp/B0B389LQCQ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 |
| Amazon | $21.99 | 2 days | 2-5V | I2C | https://www.amazon.com/Measurement-Quality-Dioxide-Detector-Replace/dp/B09SH53B58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 |
| Amazon | $13.36 | weeks  | ? | I2C | https://www.amazon.com/dp/B0CJR2SG1J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 |
| Arduino  | $48.90 | 3 days | ?** | ?** | https://store-usa.arduino.cc/collections/sensors/products/gravity-analog-co2-gas-sensor-mg-811-sensor |
| SparkFun | $19.95 |  5+ days | 3V3 | I2C | https://www.sparkfun.com/products/20844 |
| SparkFun | $29.95 |  5+ days | 3V3 | I2C | https://www.sparkfun.com/products/22858 |
| Adafruit | $44.95 | | 3.3-5V | I2C | https://www.adafruit.com/product/5187 |

*Does not include shipping \
**May require additional Arduino shield (compatible with Nano?)

&nbsp;
## CO2 Sensor Choice

Which CO2 sensor to use is a difficult choice. Well known suppliers like Arduino, SparkFun, and Adafruit likely have better support and documentation, but they are also more expensive and have costlier and slower shipping. Off brand Amazon options are cheap and ship quickly but who knows how well they work or how they they are documented.

There are a few options for CO2 sensing:
- Using "true" CO2 sensors
  - Pros: higher accuracy, direct CO2 measurement
  - Cons: more expensive
- Using "equivalent" CO2 sensors
  - Pros: Cheaper
  - Cons: Don't actually measure CO2, may require calibration, less accurate
- Using combination of "true" and "equivalent" CO2 sensors
  - Pros: single "true" sensor can be used to calibrate "equivalent" sensors
  - Cons: Even a single "true" unit is pretty expensive, extra work to
    integrate two different types of sensors

For this project, the goal is not perfect sensing but instead relative sensing
over time to get a sense of overall air circulation. Because of this, the cost
savings of cheaper CO2 equivalent sensors better meet the needs of the project
than the more accurate true CO2 sensors. Additionally, with multiple sensors
calibration can be done over all the sensors in the same environment, allowing
slight variations per sensor to be balanced out over the whole sensor group.
This means the highest priorities are cost, compatibility, and ease of use.

In the equivalent CO2 sensor space, the
[ENS160](https://www.sciosense.com/wp-content/uploads/documents/SC-001224-DS-9-ENS160-Datasheet.pdf)
appears to offer the perfect balance of quality, cost, and ease of use. For our
system, we are not able to directly solder sensors to our microcontroller PCB,
so we need to buy the sensor on a prefabricated chip with easy pin access. Both
[Sparkfun](https://www.sparkfun.com/products/20844) and
[Adafruit](https://www.adafruit.com/product/5606) offer the ENS160 presoldered
in a convenient package, though at more than double the price of the sensor
itself. Pairing the ENS160 with a temperature and humidity sensor can increase
the accuracy of the results, but for the same price it would be possible to
move into the true CO2 sensing space. We could also have a "central" Humidity
and temperature sensor, say at the hub, that transmits to all of the networked
CO2 sensors using the assumption that the indoor climate is approximately the
same for all sensors.

To move into true CO2 sensors, the
[SCD4x](https://sensirion.com/media/documents/48C4B7FB/64C134E7/Sensirion_SCD4x_Datasheet.pdf)
range of sensors provide varying degrees of accuracy, detection range, and
cost. For this project, the SCD40 has the best balance of low price and
accuracy at the desired detection range (400 - 2000 ppm). The SCD41 sits at a
slightly higher price point and has a larger detection range, but that is not
necessary for the levels of CO2 we are targeting. The only real benefit to the
SCD41 for our project would be the lower power modes that it supports. Again,
both [Sparkfun](https://www.sparkfun.com/products/22395) and
[Adafruit](https://www.adafruit.com/product/5187) provide the SCD40 on a
presoldered package, but the Adafruit product is significantly cheaper.
Adafruit also offers the [SCD41](https://www.adafruit.com/product/5190) for
only $5 more than the SCD40.

I propose we start with the
[Sparkfun ENS160](https://www.sparkfun.com/products/20844), which could either
be directly attached to the RPi via connector pins or could be attached using
the Sparkfun Qwiic system and the
[Qwiick shim](https://www.sparkfun.com/products/15794). If we feel we need more
accuracy, we could either move into the centralized Humidity/Temperature space
or order an SCD4x for calibrating the sensors.

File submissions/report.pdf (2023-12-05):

# CS 437: Internet of Things Final Project Report

### Team

- Eric Schrock (ejs9)
- Devin Schmitz (devinms3)

### Overview

We created a distributed network of CO2 sensors that report back via wifi to a central hub. The hub exposes a web interface on the LAN for accessing the data. This allows us to track variations in CO2 levels throughout a home and over time. This data could be used to understand and improve indoor air quality, leading to healthier lives.

### Motivation

todo: “Talk about the importance of this problem. Pretend you are trying to convince someone to give you funding, or purchase what you developed. You may also want to give references/citations here.”

todo: Rehash motivation section from the proposal. Maybe remove “low energy” as a design goal.

### Technical Approach

Our overall system consists of a base station connected to a network of sensors over wifi. The base station is a Raspberry Pi 4B running a server. Sensors connect to the server and periodically report CO2 measurements. The base station then presents those measurements on a website available on the local area network.

Each sensor consists of a Raspberry Pi Pico WH connected to a CO2 sensor over I2C. Each sensor runs a client that is responsible for connecting to the server on the base station, reading CO2 measurements, and sending those measurements to the base station.

1

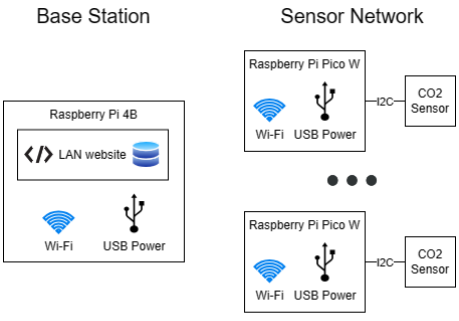
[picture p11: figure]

Figure 1: System Architecture

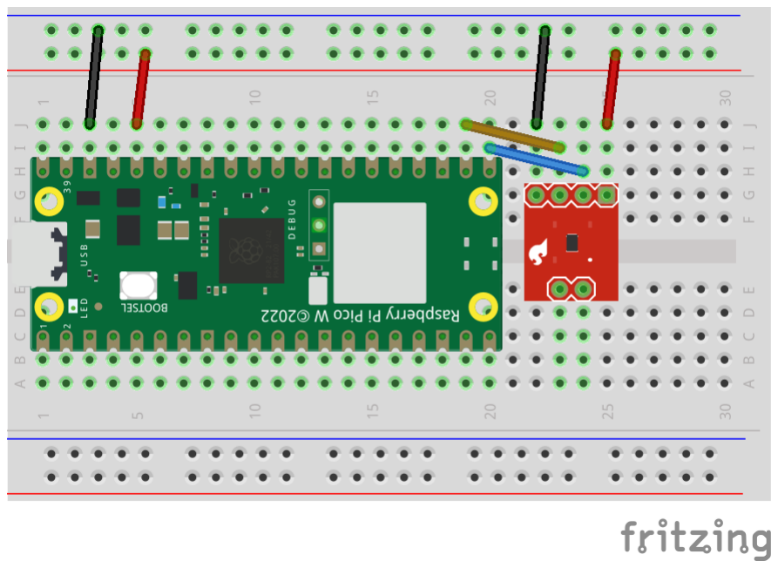
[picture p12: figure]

Figure 2: Sensor Layout

2

Note: The CO2 sensor shown in the Fritzing diagram above does not match the actual part and is only meant to give a general sense of the design.


Figure 3: Sensor Flowchart

todo: Add a high-level diagram of the server code (details belong in the next section)

todo: Add a high-level diagram of the website code (details belong in the next section)

### Implementation Details

todo: “This is where you give the details in your implementation. Talk about specific software packages you used, hardware modules, any algorithms or research papers you referred to, data structure and protocol choices, etc. You should provide at least an informal list of citations of all these external materials that went into your project.”

Ideas

- Pictures of the actual sensors (Devin’s and Eric’s versions)
- Picture of the hub
- Links to websites of parts and technologies used
- Talk through how we chose the uC (Pico vs Arduino) and CO2 sensor

3

(CO2 vs eCO2) 1
- Talk through how we chose a Raspberry Pi Pico dev language (Python vs C)
- Talk through how we chose the networking technology (wifi over BLE)
- Talk through how we chose the web technology (Flask?)

### Results

todo: “So, how did things turn out? You can provide performance results, experiences you had interacting with it, etc. Also talk about what the takeaway is - why should we care about your results? And, it is ok for things to go wrong
- what did not go right in your project, what was hard and what lessons did you learn?”

Ideas

- Talk about price (compared to CO2 sensor mentioned in the motivation section) (see the BOM in the repo README)
- Talk about productionization
– Refactor into wall wart with a custom PCB and protective case
– Solution for configuring IP address of server in each sensor
– Drive down price with economies of scale and resource usage optimization (e.g. could use a cheaper Pi with less RAM for the hub)
- Talk about changing our design from BLE to wifi
– Since sensors are wall powered instead of battery powered, power usage was not as high a priority as we initially thought in our proposal – The wifi connection was easier to implement in code and we suspect it will be more user friendly as well
- Talk about proposal timeline vs reality
– Initial design took longer than expect? (lots of options to choose between)
– HW bring up went more smoothly than expected and no 2nd prototype was needed
– Etc.

1https://electronics360.globalspec.com/article/17986/what-are-eco2-sensors

4

CO2 Data Analysis

One question we had was whether our sensors would be accurate enough to provide useful data. We found that the data trends were reliable enough to interpret and act on. For example, below is around thirteen hours of CO2 data from three different rooms. Below that is a list tying trends in the data to my (Eric’s) activity that day.


Figure 4: CO2 Data from Eric’s Home (12/4/23)

1. 11 AM - 2 PM: The bedroom CO2 level drops from its nighttime high.
2. 12 - 1 PM: The kitchen CO2 level jumps as my wife and I eat lunch.
3. 1 - 6:15 PM: The bedroom sits empty and has the lowest CO2 level. I sit at my desk in my office and my wife moves around the kitchen and adjoining living room. The kitchen CO2 level is higher than the office CO2 level because humans breath out more CO2 when we are active.
4. 6:15 PM: The kitchen CO2 level spikes when we vent the pressure cooker and then dissipate to the rest of the house, leaving every room at a higher CO2 level.
5. 6:30 - 7 PM: The kitchen CO2 level jumps as my wife and I eat supper.
6. 7 - 9:30 PM: My wife leaves for time with friends and I return to my office. The kitchen CO2 level drops below that of the office.
7. 8:15 PM: I briefly open a window in my office. The office CO2 level drops to the minimum sensor value of 400 ppm, but jumps back up as soon as I close the window.
8. 8:30 - 8:45 PM: I open a window in my office for 15 minutes. The office

5

CO2 level again drops to the minimum, but jumps back as soon as the window is closed.
9. 9:30 - 10:15 PM: My wife returns and we spend time together in the living room, near the kitchen. The kitchen CO2 level jumps.
10. 10:15 PM: We go to bed. The kitchen CO2 level drops and the bedroom CO2 level jumps.

The sensors do have a couple issues to keep in mind. First, as explained in the section on implementation details, they are measuring eCO2 which is an estimate of CO2 levels derived from TVOC levels. TVOCs can spike without CO2 spiking. For example, the data above shows a spike in the office CO2 levels at around 8 PM. This was from running a paper shredder near the sensor.

Second, the sensor results can occasionally get stuck at a high offset until they are power cycled. The CO2 level in the office jumped significantly the evening of December 4th (above) and remained high into the next day (below). I first tried opening windows throughout the house from 10:15 - 10:30 AM. The other rooms responded to this, but the office CO2 level jumped back up as soon as the windows were closed. At around noon, I power cycled the office sensor.

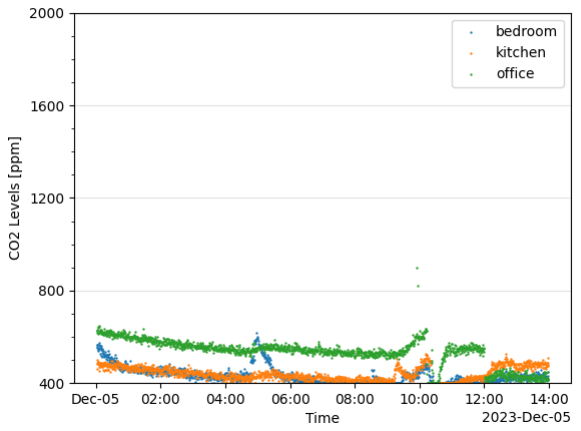
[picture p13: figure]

Figure 5: CO2 Data from Eric’s Home (12/5/23)

Despite these issues, we believe that the sensor data captured is accurate enough to drive decisions such as whether to open windows or whether to invest in a new HVAC that cycles in outdoor air in response to high indoor CO2 levels, as long as the sensor limitations are kept in mind.

6

todo (Devin): Do you have any interesting data or observations to add? How does your data compare to mine?

### Demo Videos

We recommend watching these videos on a large screen and/or setting your video player to HD/1080p.

todo: Record demo videos (we both need to contribute)

Ideas

- Eric?: Demo sensor HW and bring up (talk through HW design and demo hello.py)
- Eric? (prettier sensors): Demo sensor installation and connection to the server (talk through sensor LED transitions and show server and data logs)
- Devin?: Demo website with live and historical data. Show some of the interesting trends observed in the data.

### Project Repository

https://github.com/EricSchrock/co2-monitor

### What We Learned

Eric

todo: Add a paragraph on things learned. Compare to the things you expected to learn in the project proposal.

Ideas

- Using Python for Embedded applications
- Refresher after years without soldering
- Networking via the Python sockets lib
- Web development using Flask
- Using the Raspberry Pi Pico WH
- Importance of CO2 levels to health
- Configuring Linux startup scripts

Devin

todo: Add a paragraph on things learned. Compare to the things you expected to learn in the project proposal.

### Conclusion

In conclusion, we accomplished the high level goal of our project, to prototype a distributed, networked, and affordable CO2 monitoring solution. Along the way,

7

we tried new technologies, built new skills, and gained a deeper understanding of the quality of the air in our homes and of how it impacts our health.

8

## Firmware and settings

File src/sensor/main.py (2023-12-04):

from machine import Pin, unique_id
from network import STA_IF, STAT_CONNECTING, WLAN
from socket import socket
from time import sleep, sleep_ms

from config import SSID, PWD, IP, PORT
from ens160 import ENS160

led = Pin("LED", Pin.OUT)

wlan = WLAN(STA_IF)
wlan.active(True)
wlan.connect(SSID, PWD)
while wlan.status() == STAT_CONNECTING:
    led.toggle()
    sleep_ms(250)
if wlan.isconnected():
    led.on()

sensor = ENS160()
sensor.enable()

uid = unique_id().hex() # Unique device ID
while True:
    try:
        client = socket()
        client.connect((IP, PORT))
        client.sendall(uid.encode())
        while True:
            led.on()
            client.sendall(str(sensor.eco2()).encode())
            led.off()
            sleep(30)
    except OSError:
        client.close()
        led.on()
        sleep(60)

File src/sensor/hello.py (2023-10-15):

# Save this file to the Pico as "main.py" to have it run on startup

from machine import I2C, Pin
from time import sleep

led = Pin("LED", Pin.OUT)
i2c = I2C(0, scl=Pin("GP17"), sda=Pin("GP16"))

while True:
    opmode = 0x2
    i2c.writeto_mem(0x53, 0x10, opmode.to_bytes(1, 'little'))
    mode = int.from_bytes(i2c.readfrom_mem(0x53, 0x10, 1), 'little')
    co2 = int.from_bytes(i2c.readfrom_mem(0x53, 0x24, 2), 'little')
    print(f"co2: {co2}")
    led.on() if co2 >= 450 else led.off()
    sleep(0.5)

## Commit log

2023-09-25 Added diagram of initial sensor unit prototype
    [CO2-sensor-unit.fzz]
2023-09-25 Initial Arduino comparison
2023-09-25 Initial parts list for first prototype
2023-09-25 CO2 sensor options
2023-09-28 Add Raspberry Pi Pico to microcontrollers
2023-09-30 Add thoughts on RPi Pico WH and various CO2 sensors
2023-10-03 Updated markdown files for finalized first prototype
    [first-prototype.fzz]
2023-10-03 Updates to first prototype diagrams
    [first-prototype.fzz]
2023-10-06 Small updates to the first prototype parts list
2023-10-08 Added setup links for Pico
2023-10-08 Pico hello world
2023-10-15 Initial Wifi Server and ENS160 Sensor commit
2023-10-15 Basic I2C connection to CO2 sensor
2023-10-15 Sensor program that lights the LED when you blow on the sensor
2023-10-15 Moved sensor.py to sensor/hello.py
2023-10-15 Switched I2C pins to simplify wiring
    [first-prototype.fzz]
2023-10-15 Restructured README
    [sensor.fzz]
2023-10-16 Bill of materials
2023-10-18 Moved sensor network config to config.py
2023-10-18 Limit sensor/main.py import scope
2023-10-18 Update default I2C pins
2023-12-03 Added sensor setup instructions
2023-12-04 Revert to reading CO2 every 30 seconds
    [main.py]
2023-12-04 Added flow chart of sensor code
2023-12-04 Switch to scatter plot to better show gaps in data
2023-12-07 Sensor implementation section (first draft)
2023-12-13 Server flowchart
2023-12-13 Website host flowchart
2023-12-14 Links to sensor demos. Also spread out the demo links to make them easier to click.
